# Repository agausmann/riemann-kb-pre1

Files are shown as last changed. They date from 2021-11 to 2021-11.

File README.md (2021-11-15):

# Riemann

A pseudo-split 60% ortholinear keyboard.

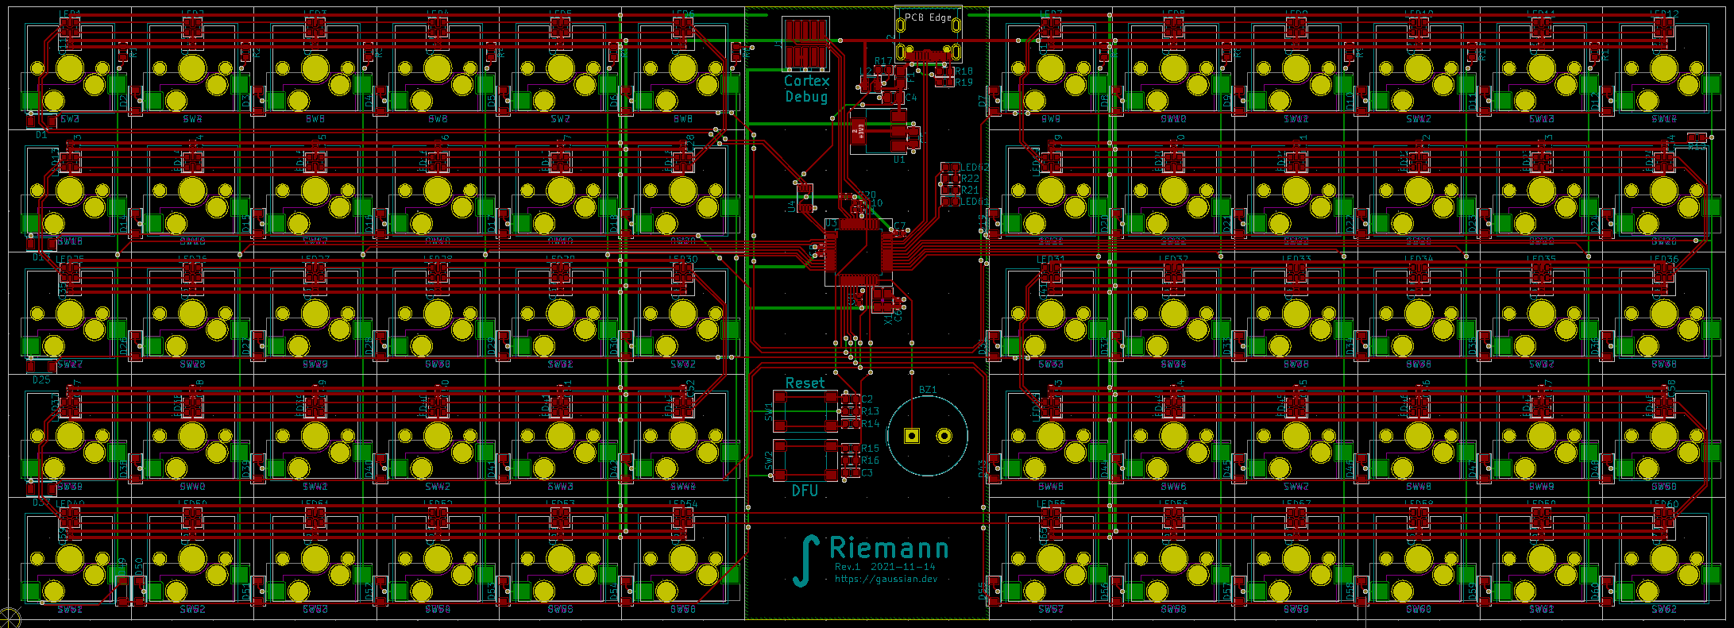
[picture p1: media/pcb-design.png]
PCB Design


## Main Features

- 60 keys in a 5x12 grid

- Supports MX-style switches

- Per-key RGB

- Hot-swappable

- QMK support (TODO)

## Design

- Designed with the features that I want, with no compromises.

- Designed to be factory-assembled, _not_ hand-soldered (I want to be able to rely on this, and I don't trust my soldering skills _that_ much).

- Microcontroller is selected to be compatible with the [Rust] programming 
language (unfortunately it does not have good support for AVR)

- PRETTY COLORS (RGB LEDs are based on the APA102 IC for that sweet, sweet
dynamic range, compared to WS2812)

[Rust]: https://rust-lang.org

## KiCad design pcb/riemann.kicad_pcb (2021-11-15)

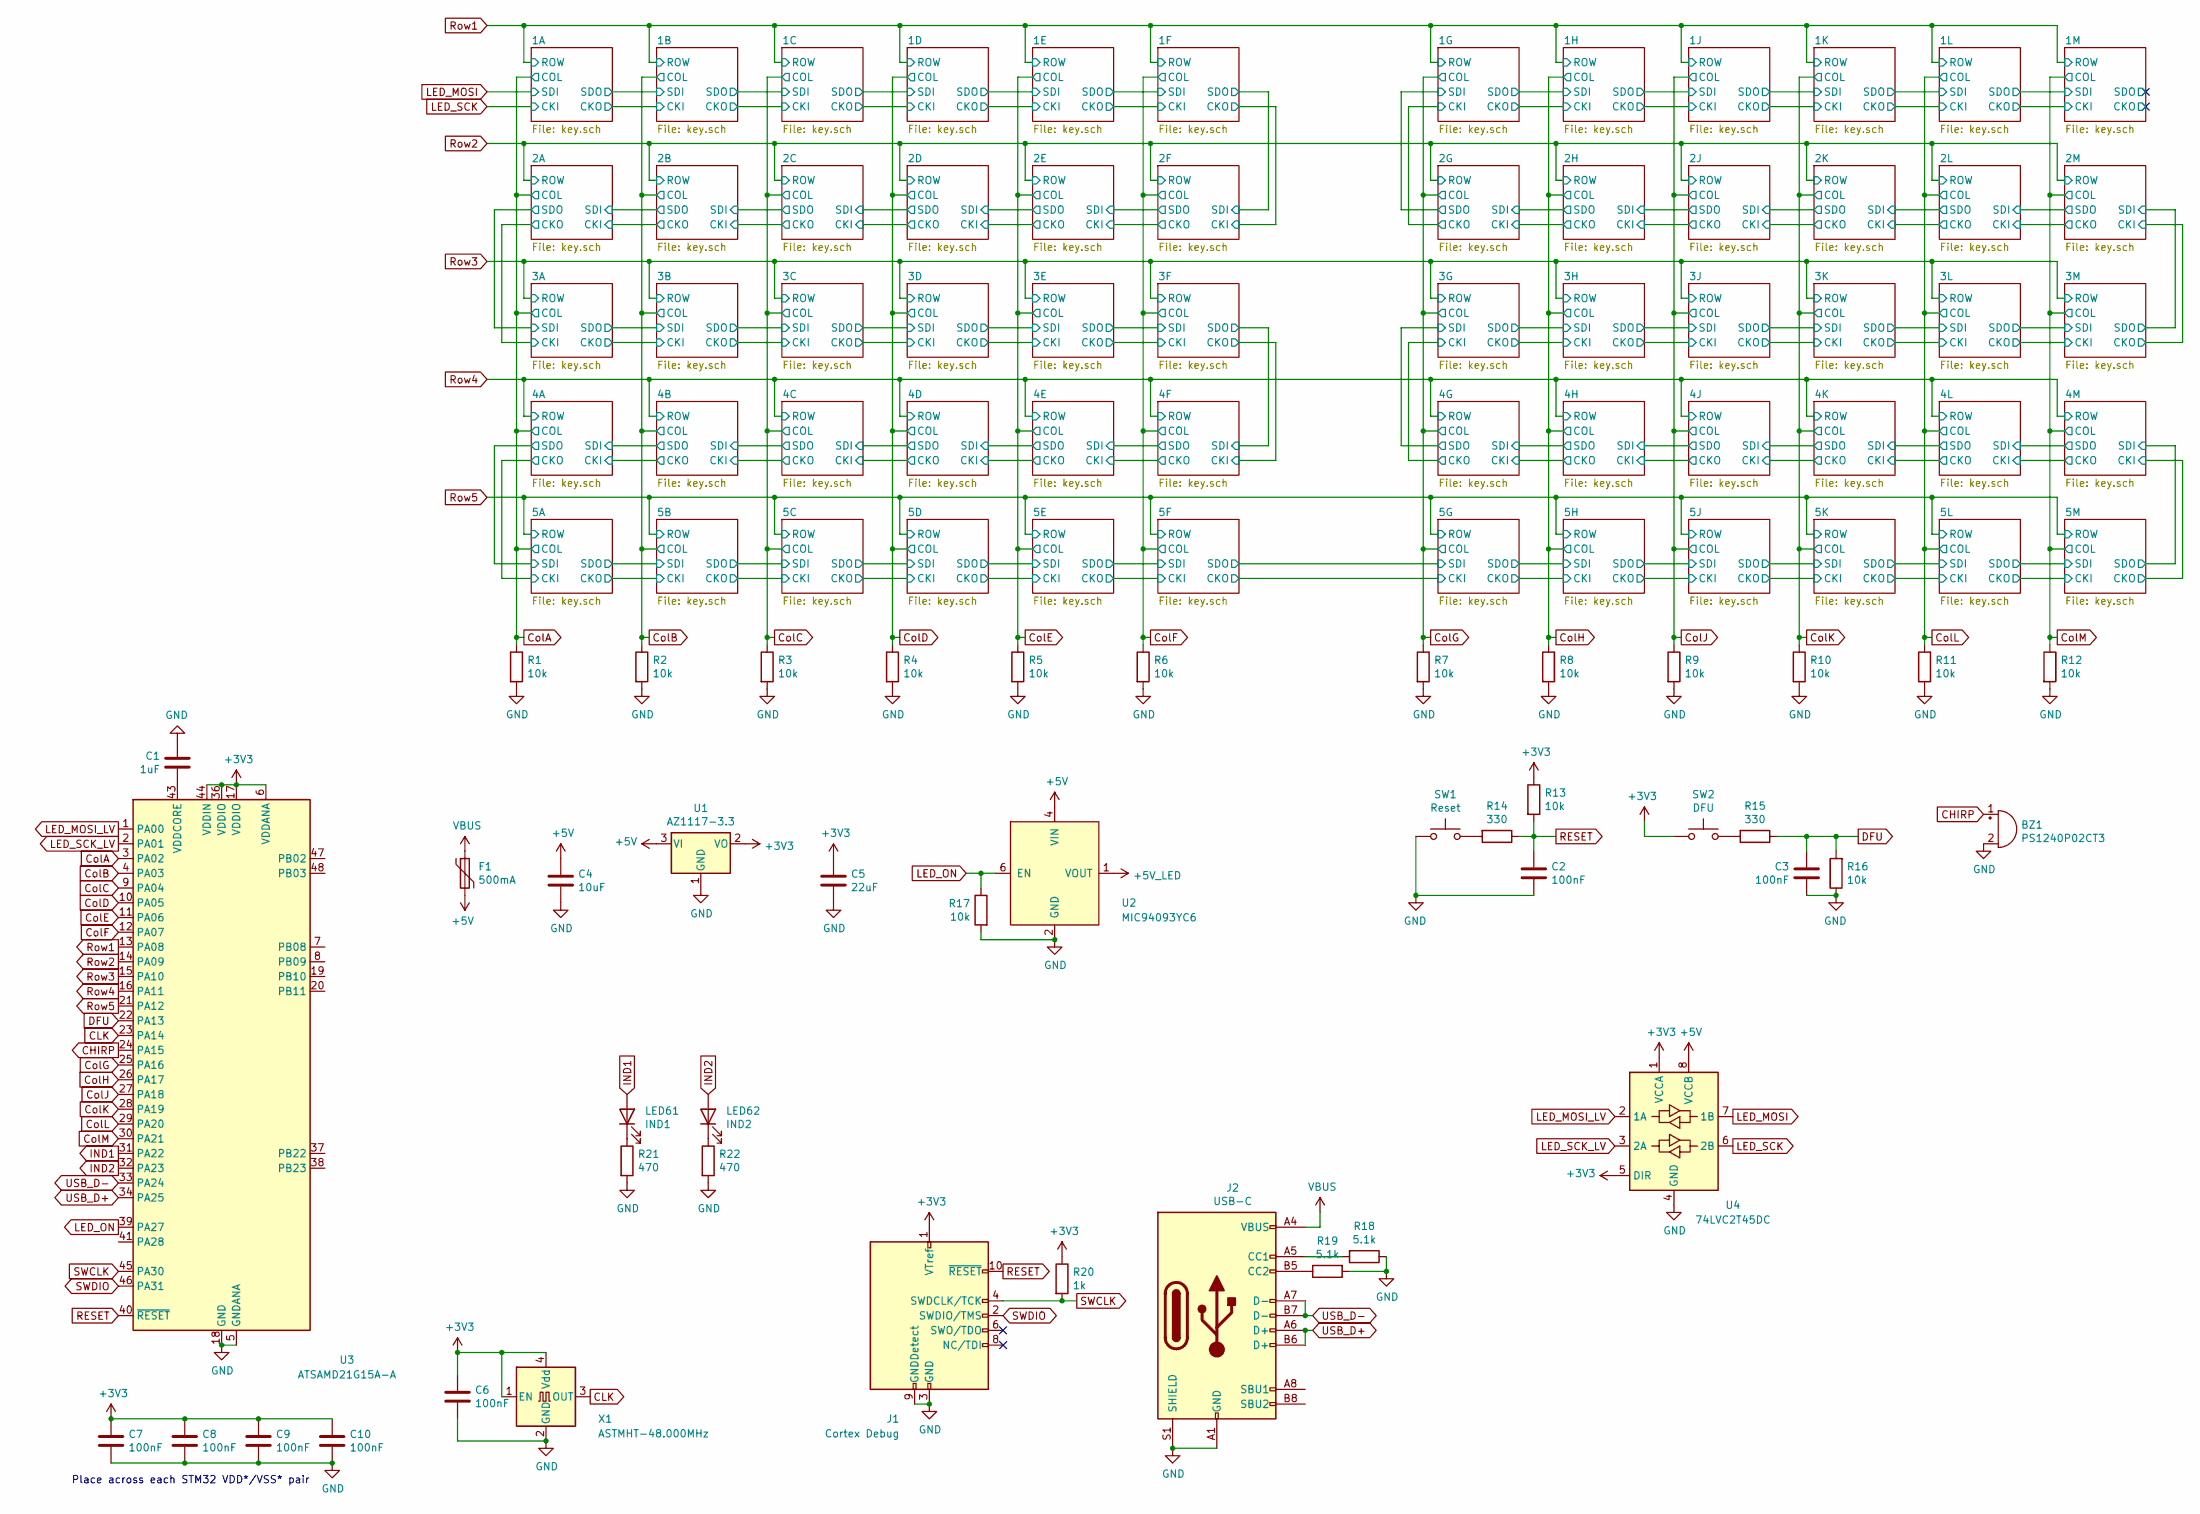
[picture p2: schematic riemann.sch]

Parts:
BZ1: PS1240P02CT3; Buzzer_TDK_PS1240P02BT_D12.2mm_H6.5mm; Mfr. Part PS1240P02CT3; Digikey 445-5229-1-ND
C1: 1uF; C_0402_1005Metric; Mfr. Part CL05A105MQ5NNNC; Digikey 1276-1235-1-ND
C2, C3: 100nF; C_0603_1608Metric; Mfr. Part CL10B104KA8NNNC; Digikey 1276-1006-1-ND
C4: 10uF; C_0805_2012Metric; Mfr. Part CL21A106KOFNNNE; Digikey 1276-2893-1-ND
C5: 22uF; C_0805_2012Metric; Mfr. Part CL21A226MOCLRNC; Digikey 1276-6780-1-ND
C6, C7, C8, C9, C10: 100nF; C_0402_1005Metric; Mfr. Part CL05A104KA5NNNC; Digikey 1276-1043-1-ND
F1: 500mA; Fuse_0805_2012Metric_Castellated; Mfr. Part 0ZCK0050FF2E; Digikey 507-1813-1-ND
J1: Cortex Debug; Samtec_FTSH-105_2x05_P1.27mm_Keyed_Vertical; Mfr. Part FTSH-105-01-L-DV-K-A-P-TR; Digikey SAM13163CT-ND
J2: USB-C; USB_C_Receptacle_GCT_USB4105; Mfr. Part USB4105-GF-A; Digikey 2073-USB4105-GF-ACT-ND
LED61: IND1; LED_0603_1608Metric; Mfr. Part 150060AS75000; Digikey 732-150060AS75000CT-ND
LED62: IND2; LED_0603_1608Metric; Mfr. Part 150060BS75000; Digikey 732-4966-1-ND
R1, R2, R3, R4, R5, R6, R7, R8, R9, R10, R11, R12, R13, R16, R17: 10k; R_0603_1608Metric; Mfr. Part RMCF0603FT10K0; Digikey RMCF0603FT10K0CT-ND
R14, R15: 330; R_0603_1608Metric; Mfr. Part RMCF0603FT330R; Digikey RMCF0603FT330RCT-ND
R18, R19: 5.1k; R_0603_1608Metric; Mfr. Part RMCF0603FT5K10; Digikey RMCF0603FT5K10CT-ND
R20: 1k; R_0402_1005Metric; Mfr. Part RMCF0402FT1K00; Digikey RMCF0402FT1K00CT-ND
R21, R22: 470; R_0603_1608Metric
SW1: Reset; SW_Push_1P1T_NO_6x6mm_H9.5mm; Mfr. Part PTS645SL43SMTR92 LFS; Digikey CKN10880CT-ND
SW2: DFU; SW_Push_1P1T_NO_6x6mm_H9.5mm; Mfr. Part PTS645SL43SMTR92 LFS; Digikey CKN10880CT-ND
U1: AZ1117-3.3; SOT-223-3_TabPin2; Mfr. Part AZ1117IH-3.3TRG1; Digikey AZ1117IH-3.3TRG1DICT-ND
U2: MIC94093YC6; SOT-363_SC-70-6; Mfr. Part MIC94093YC6-TR; Digikey 576-3490-1-ND
U3: ATSAMD21G15A-A; TQFP-48_7x7mm_P0.5mm; Mfr. Part ATSAMD21G18A-AFT; Digikey ATSAMD21G18A-AFTCT-ND
U4: 74LVC2T45DC; VSSOP-8_2.3x2mm_P0.5mm; Mfr. Part 74LVCH2T45DC,125; Digikey 1727-4596-1-ND
X1: ASTMHT-48.000MHz; Oscillator_SMD_Abracon_ASE-4Pin_3.2x2.5mm; Mfr. Part ASTMHTE-48.000MHZ-AJ-E-T; Digikey 535-13269-1-ND

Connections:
+3V3: C5.1, C6.1, C7.1, C8.1, C9.1, C10.1, J1.1 (VTref), R13.1, R20.1, SW2.2, U1.2 (VO), U3.6 (VDDANA), U3.17 (VDDIO), U3.36 (VDDIO), U3.44 (VDDIN), U4.1 (VCCA), U4.5 (DIR), X1.1 (EN), X1.4 (Vdd)
+5V: C4.1, F1.2, U1.3 (VI), U2.4 (VIN), U4.8 (VCCB)
+5V_LED: U2.1 (VOUT); also elsewhere on the board
CHIRP: BZ1.1 (-), U3.24 (PA15)
CLK: U3.23 (PA14), X1.3 (OUT)
ColA: R1.1, U3.3 (PA02); also elsewhere on the board
ColB: R2.1, U3.4 (PA03); also elsewhere on the board
ColC: R3.1, U3.9 (PA04); also elsewhere on the board
ColD: R4.1, U3.10 (PA05); also elsewhere on the board
ColE: R5.1, U3.11 (PA06); also elsewhere on the board
ColF: R6.1, U3.12 (PA07); also elsewhere on the board
ColG: R7.1, U3.25 (PA16); also elsewhere on the board
ColH: R8.1, U3.26 (PA17); also elsewhere on the board
ColJ: R9.1, U3.27 (PA18); also elsewhere on the board
ColK: R10.1, U3.28 (PA19); also elsewhere on the board
ColL: R11.1, U3.29 (PA20); also elsewhere on the board
ColM: R12.1, U3.30 (PA21); also elsewhere on the board
DFU: C3.1, R15.1, R16.2, U3.22 (PA13)
GND: BZ1.2 (+), C1.2, C2.2, C3.2, C4.2, C5.2, C6.2, C7.2, C8.2, C9.2, C10.2, J1.3 (GND), J1.5 (GND), J1.9 (GNDDetect), J2.A1 (GND), J2.A12 (GND), J2.B1 (GND), J2.B12 (GND), J2.S1 (SHIELD), R1.2, R2.2, R3.2, R4.2, R5.2, R6.2, R7.2, R8.2, R9.2, R10.2, R11.2, R12.2, R16.1, R17.2, R18.1, R19.2, R21.2, R22.2, SW1.1, U1.1 (GND), U2.2 (GND), U2.5 (GND), U3.5 (GNDANA), U3.18 (GND), U3.35 (GND), U3.42 (GND), U4.4 (GND), X1.2 (GND); also elsewhere on the board
IND1: LED61.2 (A), U3.31 (PA22)
IND2: LED62.2 (A), U3.32 (PA23)
LED_MOSI: U4.7 (1B); also elsewhere on the board
LED_MOSI_LV: U3.1 (PA00), U4.2 (1A)
LED_ON: R17.1, U2.6 (EN), U3.39 (PA27)
LED_SCK: U4.6 (2B); also elsewhere on the board
LED_SCK_LV: U3.2 (PA01), U4.3 (2A)
unnamed: C1.1, U3.43 (VDDCORE)
unnamed: J2.A5 (CC1), R18.2
unnamed: J2.B5 (CC2), R19.1
unnamed: LED61.1 (K), R21.1
unnamed: LED62.1 (K), R22.1
unnamed: R14.2, SW1.2
unnamed: R15.2, SW2.1
RESET: C2.1, J1.10 (~RESET~), R13.2, R14.1, U3.40 (~RESET)
Row1: U3.13 (PA08); also elsewhere on the board
Row2: U3.14 (PA09); also elsewhere on the board
Row3: U3.15 (PA10); also elsewhere on the board
Row4: U3.16 (PA11); also elsewhere on the board
Row5: U3.21 (PA12); also elsewhere on the board
SWCLK: J1.4 (SWDCLK/TCK), R20.2, U3.45 (PA30)
SWDIO: J1.2 (SWDIO/TMS), U3.46 (PA31)
USB_D+: J2.A6 (D+), J2.B6 (D+), U3.34 (PA25)
USB_D-: J2.A7 (D-), J2.B7 (D-), U3.33 (PA24)
VBUS: F1.1, J2.A4 (VBUS), J2.A9 (VBUS), J2.B4 (VBUS), J2.B9 (VBUS)

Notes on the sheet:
Place across each STM32 VDD*/VSS* pair

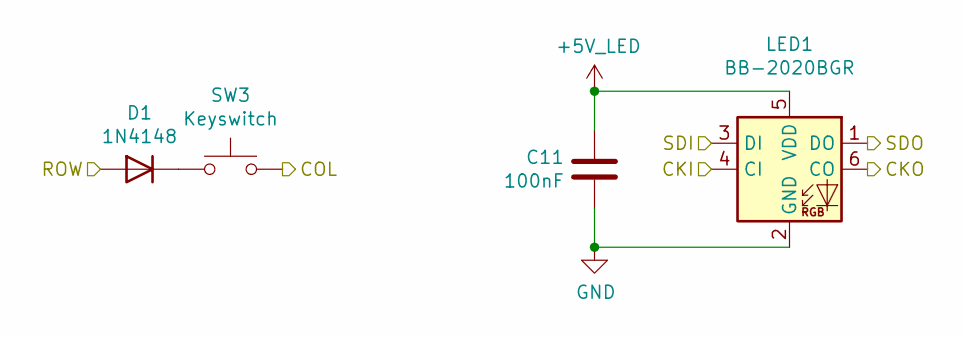
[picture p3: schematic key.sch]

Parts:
C11: 100nF; C_0402_1005Metric; Mfr. Part CL05A104KA5NNNC; Digikey 1276-1043-1-ND
D1: 1N4148; D_SOD-123; Mfr. Part 1N4148WSTR; Digikey 1655-1359-1-ND
LED1: BB-2020BGR; LED-BB-2020BGR; Mfr. Part BB-2020BGR-TRB; Digikey 2007-BB-2020BGR-TRBCT-ND
SW3: Keyswitch; SW_GateronRGB_KailhSocket_1.00u_PCB; Mfr. Part CPG151101S11

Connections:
+5V_LED: C11.2, LED1.5 (VDD); also elsewhere on the board
/1B/CKI: LED1.6 (CO); also elsewhere on the board
/1B/SDI: LED1.1 (DO); also elsewhere on the board
ColA: SW3.2; also elsewhere on the board
GND: C11.1, LED1.2 (GND); also elsewhere on the board
LED_MOSI: LED1.3 (DI); also elsewhere on the board
LED_SCK: LED1.4 (CI); also elsewhere on the board
unnamed: D1.1 (K), SW3.1
Row1: D1.2 (A); also elsewhere on the board

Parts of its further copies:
C12, C13, C14, C15, C16, C17, C18, C19, C20, C21, C22, C23, C24, C25, C26, C27, C28, C29, C30, C31, C32, C33, C34, C35, C36, C37, C38, C39, C40, C41, C42, C43, C44, C45, C46, C47, C48, C49, C50, C51, C52, C53, C54, C55, C56, C57, C58, C59, C60, C61, C62, C63, C64, C65, C66, C67, C68, C69, C70: 100nF; C_0402_1005Metric; Mfr. Part CL05A104KA5NNNC; Digikey 1276-1043-1-ND
D2, D3, D4, D5, D6, D7, D8, D9, D10, D11, D12, D13, D14, D15, D16, D17, D18, D19, D20, D21, D22, D23, D24, D25, D26, D27, D28, D29, D30, D31, D32, D33, D34, D35, D36, D37, D38, D39, D40, D41, D42, D43, D44, D45, D46, D47, D48, D49, D50, D51, D52, D53, D54, D55, D56, D57, D58, D59, D60: 1N4148; D_SOD-123; Mfr. Part 1N4148WSTR; Digikey 1655-1359-1-ND
LED2, LED3, LED4, LED5, LED6, LED7, LED8, LED9, LED10, LED11, LED12, LED13, LED14, LED15, LED16, LED17, LED18, LED19, LED20, LED21, LED22, LED23, LED24, LED25, LED26, LED27, LED28, LED29, LED30, LED31, LED32, LED33, LED34, LED35, LED36, LED37, LED38, LED39, LED40, LED41, LED42, LED43, LED44, LED45, LED46, LED47, LED48, LED49, LED50, LED51, LED52, LED53, LED54, LED55, LED56, LED57, LED58, LED59, LED60: BB-2020BGR; LED-BB-2020BGR; Mfr. Part BB-2020BGR-TRB; Digikey 2007-BB-2020BGR-TRBCT-ND
SW4, SW5, SW6, SW7, SW8, SW9, SW10, SW11, SW12, SW13, SW14, SW15, SW16, SW17, SW18, SW19, SW20, SW21, SW22, SW23, SW24, SW25, SW26, SW27, SW28, SW29, SW30, SW31, SW32, SW33, SW34, SW35, SW36, SW37, SW38, SW39, SW40, SW41, SW42, SW43, SW44, SW45, SW46, SW47, SW48, SW49, SW50, SW51, SW52, SW53, SW54, SW55, SW56, SW57, SW58, SW59, SW60, SW61, SW62: Keyswitch; SW_GateronRGB_KailhSocket_1.00u_PCB; Mfr. Part CPG151101S11

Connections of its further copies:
+5V_LED: C12.2, C13.2, C14.2, C15.2, C16.2, C17.2, C18.2, C19.2, C20.2, C21.2, C22.2, C23.2, C24.2, C25.2, C26.2, C27.2, C28.2, C29.2, C30.2, C31.2, C32.2, C33.2, C34.2, C35.2, C36.2, C37.2, C38.2, C39.2, C40.2, C41.2, C42.2, C43.2, C44.2, C45.2, C46.2, C47.2, C48.2, C49.2, C50.2, C51.2, C52.2, C53.2, C54.2, C55.2, C56.2, C57.2, C58.2, C59.2, C60.2, C61.2, C62.2, C63.2, C64.2, C65.2, C66.2, C67.2, C68.2, C69.2, C70.2, LED2.5 (VDD), LED3.5 (VDD), LED4.5 (VDD), LED5.5 (VDD), LED6.5 (VDD), LED7.5 (VDD), LED8.5 (VDD), LED9.5 (VDD), LED10.5 (VDD), LED11.5 (VDD), LED12.5 (VDD), LED13.5 (VDD), LED14.5 (VDD), LED15.5 (VDD), LED16.5 (VDD), LED17.5 (VDD), LED18.5 (VDD), LED19.5 (VDD), LED20.5 (VDD), LED21.5 (VDD), LED22.5 (VDD), LED23.5 (VDD), LED24.5 (VDD), LED25.5 (VDD), LED26.5 (VDD), LED27.5 (VDD), LED28.5 (VDD), LED29.5 (VDD), LED30.5 (VDD), LED31.5 (VDD), LED32.5 (VDD), LED33.5 (VDD), LED34.5 (VDD), LED35.5 (VDD), LED36.5 (VDD), LED37.5 (VDD), LED38.5 (VDD), LED39.5 (VDD), LED40.5 (VDD), LED41.5 (VDD), LED42.5 (VDD), LED43.5 (VDD), LED44.5 (VDD), LED45.5 (VDD), LED46.5 (VDD), LED47.5 (VDD), LED48.5 (VDD), LED49.5 (VDD), LED50.5 (VDD), LED51.5 (VDD), LED52.5 (VDD), LED53.5 (VDD), LED54.5 (VDD), LED55.5 (VDD), LED56.5 (VDD), LED57.5 (VDD), LED58.5 (VDD), LED59.5 (VDD), LED60.5 (VDD); also elsewhere on the board
/1B/CKI: LED2.4 (CI); also elsewhere on the board
/1B/SDI: LED2.3 (DI); also elsewhere on the board
/1C/CKI: LED2.6 (CO), LED3.4 (CI)
/1C/SDI: LED2.1 (DO), LED3.3 (DI)
/1D/CKI: LED3.6 (CO), LED4.4 (CI)
/1D/SDI: LED3.1 (DO), LED4.3 (DI)
/1E/CKI: LED4.6 (CO), LED5.4 (CI)
/1E/SDI: LED4.1 (DO), LED5.3 (DI)
/1F/CKI: LED5.6 (CO), LED6.4 (CI)
/1F/SDI: LED5.1 (DO), LED6.3 (DI)
/1G/CKI: LED7.4 (CI), LED19.6 (CO)
/1G/SDI: LED7.3 (DI), LED19.1 (DO)
/1H/CKI: LED7.6 (CO), LED8.4 (CI)
/1H/SDI: LED7.1 (DO), LED8.3 (DI)
/1J/CKI: LED8.6 (CO), LED9.4 (CI)
/1J/SDI: LED8.1 (DO), LED9.3 (DI)
/1K/CKI: LED9.6 (CO), LED10.4 (CI)
/1K/SDI: LED9.1 (DO), LED10.3 (DI)
/1L/CKI: LED10.6 (CO), LED11.4 (CI)
/1L/SDI: LED10.1 (DO), LED11.3 (DI)
/1M/CKI: LED11.6 (CO), LED12.4 (CI)
/1M/CKO: LED12.6 (CO)
/1M/SDI: LED11.1 (DO), LED12.3 (DI)
/1M/SDO: LED12.1 (DO)
/2A/CKI: LED13.4 (CI), LED14.6 (CO)
/2A/SDI: LED13.3 (DI), LED14.1 (DO)
/2B/CKI: LED14.4 (CI), LED15.6 (CO)
/2B/SDI: LED14.3 (DI), LED15.1 (DO)
/2C/CKI: LED15.4 (CI), LED16.6 (CO)
/2C/SDI: LED15.3 (DI), LED16.1 (DO)
/2D/CKI: LED16.4 (CI), LED17.6 (CO)
/2D/SDI: LED16.3 (DI), LED17.1 (DO)
/2E/CKI: LED17.4 (CI), LED18.6 (CO)
/2E/SDI: LED17.3 (DI), LED18.1 (DO)
/2F/CKI: LED6.6 (CO), LED18.4 (CI)
/2F/SDI: LED6.1 (DO), LED18.3 (DI)
/2G/CKI: LED19.4 (CI), LED20.6 (CO)
/2G/SDI: LED19.3 (DI), LED20.1 (DO)
/2H/CKI: LED20.4 (CI), LED21.6 (CO)
/2H/SDI: LED20.3 (DI), LED21.1 (DO)
/2J/CKI: LED21.4 (CI), LED22.6 (CO)
/2J/SDI: LED21.3 (DI), LED22.1 (DO)
/2K/CKI: LED22.4 (CI), LED23.6 (CO)
/2K/SDI: LED22.3 (DI), LED23.1 (DO)
/2L/CKI: LED23.4 (CI), LED24.6 (CO)
/2L/SDI: LED23.3 (DI), LED24.1 (DO)
/2M/CKI: LED24.4 (CI), LED36.6 (CO)
/2M/SDI: LED24.3 (DI), LED36.1 (DO)
/3A/CKI: LED13.6 (CO), LED25.4 (CI)
/3A/SDI: LED13.1 (DO), LED25.3 (DI)
/3B/CKI: LED25.6 (CO), LED26.4 (CI)
/3B/SDI: LED25.1 (DO), LED26.3 (DI)
/3C/CKI: LED26.6 (CO), LED27.4 (CI)
/3C/SDI: LED26.1 (DO), LED27.3 (DI)
/3D/CKI: LED27.6 (CO), LED28.4 (CI)
/3D/SDI: LED27.1 (DO), LED28.3 (DI)
/3E/CKI: LED28.6 (CO), LED29.4 (CI)
/3E/SDI: LED28.1 (DO), LED29.3 (DI)
/3F/CKI: LED29.6 (CO), LED30.4 (CI)
/3F/SDI: LED29.1 (DO), LED30.3 (DI)
/3G/CKI: LED31.4 (CI), LED43.6 (CO)
/3G/SDI: LED31.3 (DI), LED43.1 (DO)
/3H/CKI: LED31.6 (CO), LED32.4 (CI)
/3H/SDI: LED31.1 (DO), LED32.3 (DI)
/3J/CKI: LED32.6 (CO), LED33.4 (CI)
/3J/SDI: LED32.1 (DO), LED33.3 (DI)
/3K/CKI: LED33.6 (CO), LED34.4 (CI)
/3K/SDI: LED33.1 (DO), LED34.3 (DI)
/3L/CKI: LED34.6 (CO), LED35.4 (CI)
/3L/SDI: LED34.1 (DO), LED35.3 (DI)
/3M/CKI: LED35.6 (CO), LED36.4 (CI)
/3M/SDI: LED35.1 (DO), LED36.3 (DI)
/4A/CKI: LED37.4 (CI), LED38.6 (CO)
/4A/SDI: LED37.3 (DI), LED38.1 (DO)
/4B/CKI: LED38.4 (CI), LED39.6 (CO)
/4B/SDI: LED38.3 (DI), LED39.1 (DO)
/4C/CKI: LED39.4 (CI), LED40.6 (CO)
/4C/SDI: LED39.3 (DI), LED40.1 (DO)
/4D/CKI: LED40.4 (CI), LED41.6 (CO)
/4D/SDI: LED40.3 (DI), LED41.1 (DO)
/4E/CKI: LED41.4 (CI), LED42.6 (CO)
/4E/SDI: LED41.3 (DI), LED42.1 (DO)
/4F/CKI: LED30.6 (CO), LED42.4 (CI)
/4F/SDI: LED30.1 (DO), LED42.3 (DI)
/4G/CKI: LED43.4 (CI), LED44.6 (CO)
/4G/SDI: LED43.3 (DI), LED44.1 (DO)
/4H/CKI: LED44.4 (CI), LED45.6 (CO)
/4H/SDI: LED44.3 (DI), LED45.1 (DO)
/4J/CKI: LED45.4 (CI), LED46.6 (CO)
/4J/SDI: LED45.3 (DI), LED46.1 (DO)
/4K/CKI: LED46.4 (CI), LED47.6 (CO)
/4K/SDI: LED46.3 (DI), LED47.1 (DO)
/4L/CKI: LED47.4 (CI), LED48.6 (CO)
/4L/SDI: LED47.3 (DI), LED48.1 (DO)
/4M/CKI: LED48.4 (CI), LED60.6 (CO)
/4M/SDI: LED48.3 (DI), LED60.1 (DO)
/5A/CKI: LED37.6 (CO), LED49.4 (CI)
/5A/SDI: LED37.1 (DO), LED49.3 (DI)
/5B/CKI: LED49.6 (CO), LED50.4 (CI)
/5B/SDI: LED49.1 (DO), LED50.3 (DI)
/5C/CKI: LED50.6 (CO), LED51.4 (CI)
/5C/SDI: LED50.1 (DO), LED51.3 (DI)
/5D/CKI: LED51.6 (CO), LED52.4 (CI)
/5D/SDI: LED51.1 (DO), LED52.3 (DI)
/5E/CKI: LED52.6 (CO), LED53.4 (CI)
/5E/SDI: LED52.1 (DO), LED53.3 (DI)
/5F/CKI: LED53.6 (CO), LED54.4 (CI)
/5F/SDI: LED53.1 (DO), LED54.3 (DI)
/5G/CKI: LED54.6 (CO), LED55.4 (CI)
/5G/SDI: LED54.1 (DO), LED55.3 (DI)
/5H/CKI: LED55.6 (CO), LED56.4 (CI)
/5H/SDI: LED55.1 (DO), LED56.3 (DI)
/5J/CKI: LED56.6 (CO), LED57.4 (CI)
/5J/SDI: LED56.1 (DO), LED57.3 (DI)
/5K/CKI: LED57.6 (CO), LED58.4 (CI)
/5K/SDI: LED57.1 (DO), LED58.3 (DI)
/5L/CKI: LED58.6 (CO), LED59.4 (CI)
/5L/SDI: LED58.1 (DO), LED59.3 (DI)
/5M/CKI: LED59.6 (CO), LED60.4 (CI)
/5M/SDI: LED59.1 (DO), LED60.3 (DI)
ColA: SW15.2, SW27.2, SW39.2, SW51.2; also elsewhere on the board
ColB: SW4.2, SW16.2, SW28.2, SW40.2, SW52.2; also elsewhere on the board
ColC: SW5.2, SW17.2, SW29.2, SW41.2, SW53.2; also elsewhere on the board
ColD: SW6.2, SW18.2, SW30.2, SW42.2, SW54.2; also elsewhere on the board
ColE: SW7.2, SW19.2, SW31.2, SW43.2, SW55.2; also elsewhere on the board
ColF: SW8.2, SW20.2, SW32.2, SW44.2, SW56.2; also elsewhere on the board
ColG: SW9.2, SW21.2, SW33.2, SW45.2, SW57.2; also elsewhere on the board
ColH: SW10.2, SW22.2, SW34.2, SW46.2, SW58.2; also elsewhere on the board
ColJ: SW11.2, SW23.2, SW35.2, SW47.2, SW59.2; also elsewhere on the board
ColK: SW12.2, SW24.2, SW36.2, SW48.2, SW60.2; also elsewhere on the board
ColL: SW13.2, SW25.2, SW37.2, SW49.2, SW61.2; also elsewhere on the board
ColM: SW14.2, SW26.2, SW38.2, SW50.2, SW62.2; also elsewhere on the board
GND: C12.1, C13.1, C14.1, C15.1, C16.1, C17.1, C18.1, C19.1, C20.1, C21.1, C22.1, C23.1, C24.1, C25.1, C26.1, C27.1, C28.1, C29.1, C30.1, C31.1, C32.1, C33.1, C34.1, C35.1, C36.1, C37.1, C38.1, C39.1, C40.1, C41.1, C42.1, C43.1, C44.1, C45.1, C46.1, C47.1, C48.1, C49.1, C50.1, C51.1, C52.1, C53.1, C54.1, C55.1, C56.1, C57.1, C58.1, C59.1, C60.1, C61.1, C62.1, C63.1, C64.1, C65.1, C66.1, C67.1, C68.1, C69.1, C70.1, LED2.2 (GND), LED3.2 (GND), LED4.2 (GND), LED5.2 (GND), LED6.2 (GND), LED7.2 (GND), LED8.2 (GND), LED9.2 (GND), LED10.2 (GND), LED11.2 (GND), LED12.2 (GND), LED13.2 (GND), LED14.2 (GND), LED15.2 (GND), LED16.2 (GND), LED17.2 (GND), LED18.2 (GND), LED19.2 (GND), LED20.2 (GND), LED21.2 (GND), LED22.2 (GND), LED23.2 (GND), LED24.2 (GND), LED25.2 (GND), LED26.2 (GND), LED27.2 (GND), LED28.2 (GND), LED29.2 (GND), LED30.2 (GND), LED31.2 (GND), LED32.2 (GND), LED33.2 (GND), LED34.2 (GND), LED35.2 (GND), LED36.2 (GND), LED37.2 (GND), LED38.2 (GND), LED39.2 (GND), LED40.2 (GND), LED41.2 (GND), LED42.2 (GND), LED43.2 (GND), LED44.2 (GND), LED45.2 (GND), LED46.2 (GND), LED47.2 (GND), LED48.2 (GND), LED49.2 (GND), LED50.2 (GND), LED51.2 (GND), LED52.2 (GND), LED53.2 (GND), LED54.2 (GND), LED55.2 (GND), LED56.2 (GND), LED57.2 (GND), LED58.2 (GND), LED59.2 (GND), LED60.2 (GND); also elsewhere on the board
unnamed: D2.1 (K), SW4.1
unnamed: D3.1 (K), SW5.1
unnamed: D4.1 (K), SW6.1
unnamed: D5.1 (K), SW7.1
unnamed: D6.1 (K), SW8.1
unnamed: D7.1 (K), SW9.1
unnamed: D8.1 (K), SW10.1
unnamed: D9.1 (K), SW11.1
unnamed: D10.1 (K), SW12.1
unnamed: D11.1 (K), SW13.1
unnamed: D12.1 (K), SW14.1
unnamed: D13.1 (K), SW15.1
unnamed: D14.1 (K), SW16.1
unnamed: D15.1 (K), SW17.1
unnamed: D16.1 (K), SW18.1
unnamed: D17.1 (K), SW19.1
unnamed: D18.1 (K), SW20.1
unnamed: D19.1 (K), SW21.1
unnamed: D20.1 (K), SW22.1
unnamed: D21.1 (K), SW23.1
unnamed: D22.1 (K), SW24.1
unnamed: D23.1 (K), SW25.1
unnamed: D24.1 (K), SW26.1
unnamed: D25.1 (K), SW27.1
unnamed: D26.1 (K), SW28.1
unnamed: D27.1 (K), SW29.1
unnamed: D28.1 (K), SW30.1
unnamed: D29.1 (K), SW31.1
unnamed: D30.1 (K), SW32.1
unnamed: D31.1 (K), SW33.1
unnamed: D32.1 (K), SW34.1
unnamed: D33.1 (K), SW35.1
unnamed: D34.1 (K), SW36.1
unnamed: D35.1 (K), SW37.1
unnamed: D36.1 (K), SW38.1
unnamed: D37.1 (K), SW39.1
unnamed: D38.1 (K), SW40.1
unnamed: D39.1 (K), SW41.1
unnamed: D40.1 (K), SW42.1
unnamed: D41.1 (K), SW43.1
unnamed: D42.1 (K), SW44.1
unnamed: D43.1 (K), SW45.1
unnamed: D44.1 (K), SW46.1
unnamed: D45.1 (K), SW47.1
unnamed: D46.1 (K), SW48.1
unnamed: D47.1 (K), SW49.1
unnamed: D48.1 (K), SW50.1
unnamed: D49.1 (K), SW51.1
unnamed: D50.1 (K), SW52.1
unnamed: D51.1 (K), SW53.1
unnamed: D52.1 (K), SW54.1
unnamed: D53.1 (K), SW55.1
unnamed: D54.1 (K), SW56.1
unnamed: D55.1 (K), SW57.1
unnamed: D56.1 (K), SW58.1
unnamed: D57.1 (K), SW59.1
unnamed: D58.1 (K), SW60.1
unnamed: D59.1 (K), SW61.1
unnamed: D60.1 (K), SW62.1
Row1: D2.2 (A), D3.2 (A), D4.2 (A), D5.2 (A), D6.2 (A), D7.2 (A), D8.2 (A), D9.2 (A), D10.2 (A), D11.2 (A), D12.2 (A); also elsewhere on the board
Row2: D13.2 (A), D14.2 (A), D15.2 (A), D16.2 (A), D17.2 (A), D18.2 (A), D19.2 (A), D20.2 (A), D21.2 (A), D22.2 (A), D23.2 (A), D24.2 (A); also elsewhere on the board
Row3: D25.2 (A), D26.2 (A), D27.2 (A), D28.2 (A), D29.2 (A), D30.2 (A), D31.2 (A), D32.2 (A), D33.2 (A), D34.2 (A), D35.2 (A), D36.2 (A); also elsewhere on the board
Row4: D37.2 (A), D38.2 (A), D39.2 (A), D40.2 (A), D41.2 (A), D42.2 (A), D43.2 (A), D44.2 (A), D45.2 (A), D46.2 (A), D47.2 (A), D48.2 (A); also elsewhere on the board
Row5: D49.2 (A), D50.2 (A), D51.2 (A), D52.2 (A), D53.2 (A), D54.2 (A), D55.2 (A), D56.2 (A), D57.2 (A), D58.2 (A), D59.2 (A), D60.2 (A); also elsewhere on the board

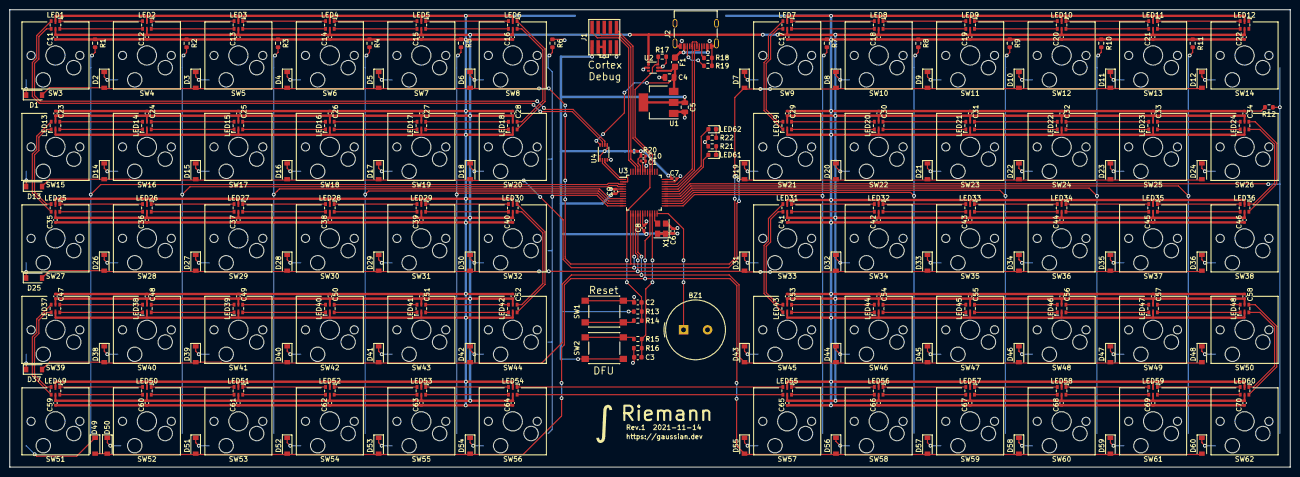
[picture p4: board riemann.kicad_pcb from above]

Board: 2 copper layers, 266.7 x 95.2 mm, 285 parts (0 on the bottom side), 222 nets.

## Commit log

2021-11-14 Initial design
    [key.sch, riemann.kicad_pcb, riemann.sch]
2021-11-14 Move PCB design files into a subfolder
    [key.sch, riemann.kicad_pcb, riemann.sch]
2021-11-15 Add branding to PCB
    [riemann.kicad_pcb]
2021-11-15 Add PCB design screenshot to README
